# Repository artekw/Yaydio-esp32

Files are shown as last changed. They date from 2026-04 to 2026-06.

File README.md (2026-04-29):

# Yaydio 📻

**No more scratched CDs!**

**Yaydio** is a portable music player designed for kids, ditching the hassle of
CDs in favor of easy-to-use keycards.

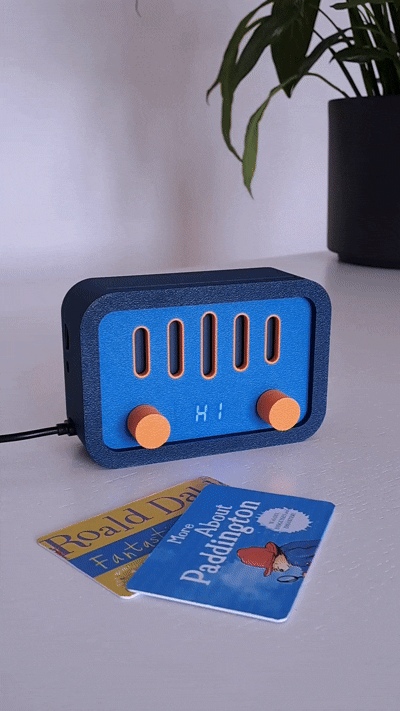
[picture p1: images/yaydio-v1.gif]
Yaydio
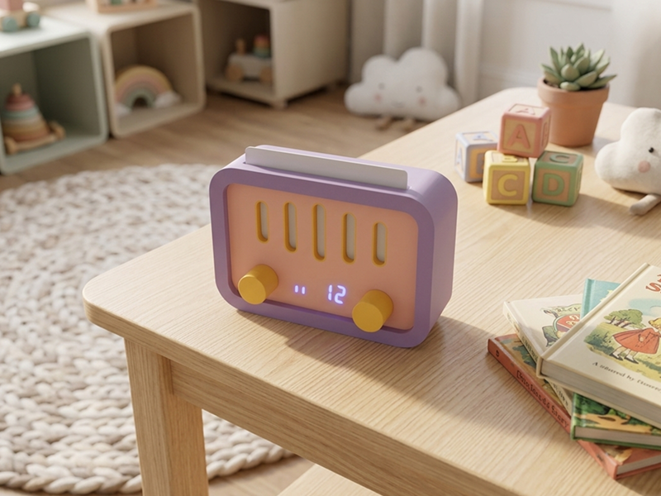
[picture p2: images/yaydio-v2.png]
Yaydio v2 (Based on real photo, scenery generated by AI)
|  |  |
| --- | --- |
| V1 | Battery powered V2 |

## ✨ Features

- **Keycard playback:** Insert a keycard to instantly play an album.
- **Simple controls:** Play/pause, next/previous track, volume up/down.
- **Audio options:** Built-in speaker or connect headphones via the 3.5mm jack.
- **Long battery life:** Over 12 hours of play time.
- **High capacity:**
  - Up to 999 songs per album
  - Up to 9999 albums
  - Up to 65535 songs in total
  - Supports micro SD cards up to 32GB.
- **MP3 compatibility:** Plays all your favorite MP3 files.
- **Affordable & accessible:** Works with cost-effective MF S50 RFID keycards.

## 🕹️ Controls

#### Play / pause

- Inserting a keycard into the **Yaydio** will automatically start the playback.
- Press the left knob to pause or resume the playback.
- Remove the keycard to stop the playback.

#### Volume

- Turn the left knob to increase or decrease the volume.

#### Next / previous track

- Turn the right knob to skip to the next or previous track.

#### Random playback

- Press the right knob to toggle random mode on or off.
- When enabled, the **Yaydio** will pick the next track from the album at
  random.

#### Assign an album to a keycard

1. Insert the keycard into the **Yaydio**.
2. Press the left and right knobs simultaneously.
3. Turn the right knob to select the album number.
4. Press the right knob to write the album number to the keycard.

## 💿 Adding albums (NEW WAY)

1. Download [Yaydio SD Flash](https://github.com/JakesMD/Yaydio-SD-Flash) for
   your platform.
2. Format the SD card to FAT16 or FAT32.
3. In the **Yaydio SD Flash** app:
   1. Create your albums.
   2. Create a new deck and select the albums to be on it.
   3. Write the deck to the SD card.

## 💿 Adding albums (OLD WAY)

#### Prepare the SD card

1. Format the SD card to FAT16 or FAT32 and name it `YAYDIO`.
2. Copy the `README.md` file onto the SD card.
3. Windows only: Download
   [DriveSort](https://www.anerty.net/software/file/DriveSort/?lang=en) and copy
   `DriveSort.exe` onto the SD card.
4. macOS only: Download [FatDriveSorter](https://fat-drive-sorter.netlify.app)
   and copy `FatDriveSorter.app` onto the SD card.

#### Copy albums to the SD card

1. Create a new folder named `0001`, where "1" represents the next album number.
2. Copy the album's songs into the folder you created.
3. Rename the first song of the album to `001.mp3`.
4. Repeat steps 1-3 for each album.

#### Sort the SD card

1. Windows only: Use `DriveSort` to sort the files alphabetically in the SD
   card's table.
   - Sort by `long name` and `ascending`.
   - Remember to press the save button.
   - You may need to sort every new folder individually and press save after
     each one.
2. macOS only: Use `FatDriveSorter` to sort the files alphabetically in the SD
   card's table.
   - Next to `Order:` select `Directories first`.
   - Tick the box next to `Case-sensitive:`.

## 🔨 Make your own

### 🧱 Parts

I've added an Amazon link for each part so you know what to look for. You'll
probably find the parts much cheaper in other stores.

- [x] 1 x Arduino Nano clone with USB-C port (pin headers not soldered on)
      ([Amazon.de](https://www.amazon.de/dp/B0D8WDV1K7))
- [x] 1 x PN532 NFC Module V3 ([Amazon.de](https://www.amazon.de/dp/B07YDG6X2V))
- [x] 1 x DY-SV5W Voice Module
      ([Amazon.de](https://www.amazon.de/dp/B09SZB73CG)) Note: Some modules
      don't come with a 1K Ohm resistor on the RXD pin. If this is the case,
      you'll have to connect D13 and the RXD pin with a 1K Ohm resistor
      ([see this](https://github.com/SnijderC/dyplayer/tree/main?tab=readme-ov-file#wiring-the-module)).
- [x] 1 x 4-digit 7-segment 0.36 inch display with TM1637 driver chip
      ([Amazon.de](https://www.amazon.de/dp/B0BCGF2R2T))
- [x] 2 x Rotary encoder with button and 15 mm D-shaft (not the KY-040 module!)
      ([Amazon.de](https://www.amazon.de/dp/B0DQKS8MBS))
- [x] 1 x Limit switch 12.8mm x 5.8mm
      ([Amazon.de](https://www.amazon.de/dp/B081TXMD4K))
- [x] 1 x Speaker 3W 8Ohms 70mm x 30mm x 15mm
      ([Amazon.de](https://amzn.eu/d/06Lj1tKR))
- [x] 1 x SM5308 battery charger module
      ([Amazon.de](https://www.amazon.de/dp/B0BGPGM4DH))
- [x] 1 x Battery 3.7V 3000mAh Li-ion 18650
      ([Amazon.de](https://www.amazon.de/dp/B0DZHL2WB6))
- [x] A bunch of 13.56 MHz MF S50 ISO14443 (Mifare Classic) RFID keycards
      ([Amazon.de](https://www.amazon.de/dp/B07TVJPTM7)) Note: If you plan on
      making multiple Yaydios sharing the same keycards, make sure you get
      keycards that aren't "magic". The cards must have a fixed UID that is not
      encrypted or reprogrammable.
- [x] Optional: 1 x Double-sided PCB board 20 x 80mm with 168 holes
      ([Amazon.de](https://www.amazon.de/dp/B0734XYJPM))
- [x] A bunch of wires ([Amazon.de](https://www.amazon.de/dp/B08MBXTRCG))

### 🧵 Wiring

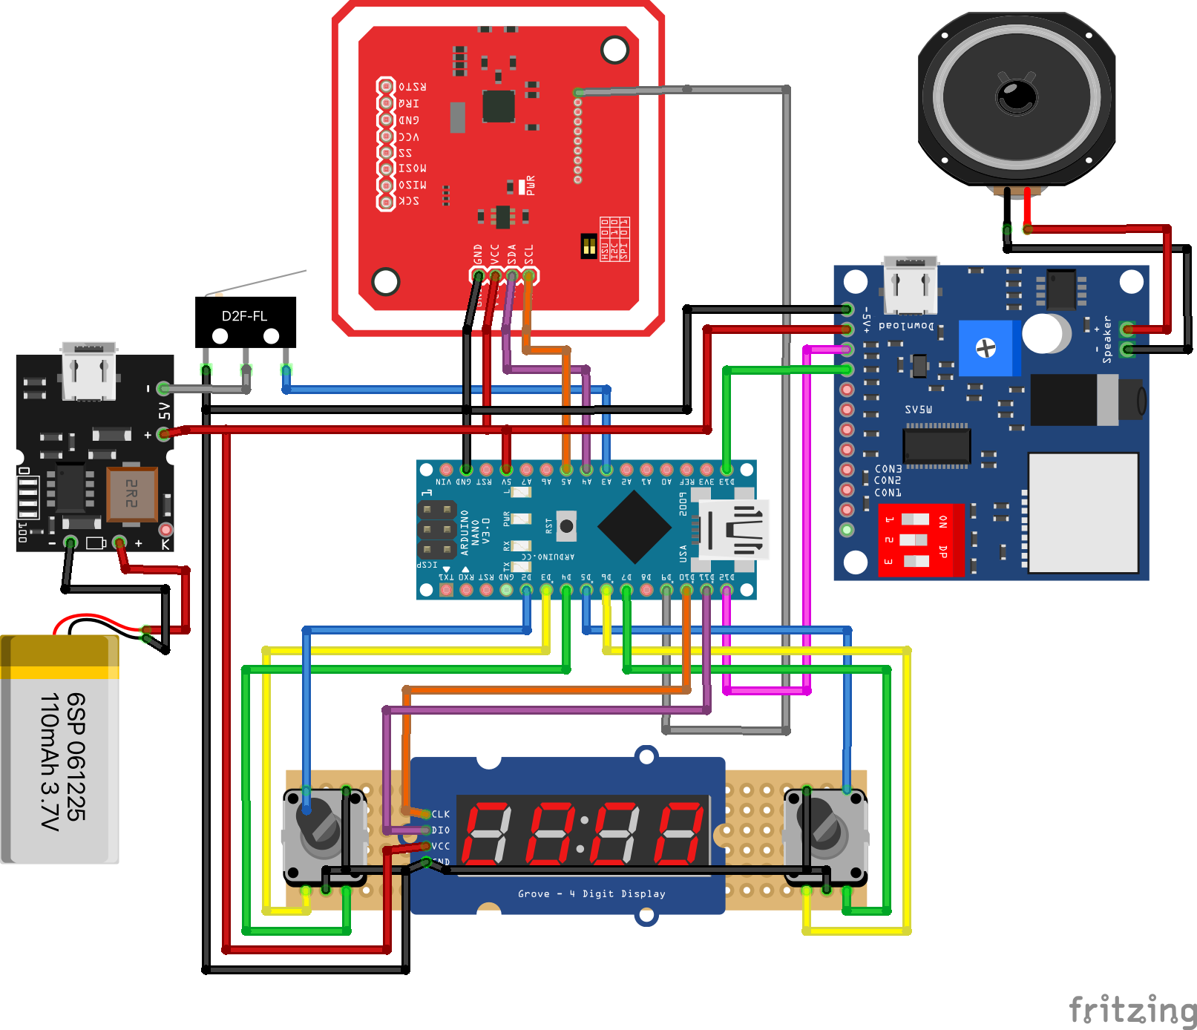
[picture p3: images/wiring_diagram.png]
Wiring Diagram


| Left Rotary Encoder | Arduino Nano |
| --- | --- |
| SW | D2 |
| SW GND | GND |
| DT | D3 |
| CLK | D4 |
| GND | GND |

| Right Rotary Encoder | Arduino Nano |
| --- | --- |
| SW | D5 |
| SW GND | GND |
| DT | D6 |
| CLK | D7 |
| GND | GND |

| 4-Digit 7-Segment 0.36 Inch TM1637 | Arduino Nano |
| --- | --- |
| CLK | D10 |
| DIO | D11 |
| GND | GND |
| 5V | 5V |

| Card Switch | |
| --- | --- |
| COM | Arduino GND |
| NO | Battery Module GND |
| NC | A3 |

| SM5308 Battery Module | |
| --- | --- |
| 5V | Arduino 5V |
| GND | Card Switch NO |
| B+ | Battery + |
| B- | Battery - |

| PN532 NFC Module V3 | Arduino Nano |
| --- | --- |
| GND | GND |
| VCC | 5V |
| SDA | A4 |
| SCL | A5 |
| RSTPDN | D9 |
| Switches: ON, OFF (I2C mode) | |

| DY-SV5W Voice Module | |
| --- | --- |
| - | Arduino GND |
| + | Arduino 5V  |
| TXD | Arduino D12 |
| RXD | Arduino D13 |
| Speaker + | Speaker + |
| Speaker - | Speaker - |
| Switches: OFF, OFF, ON (UART mode) | |

### 🏗️ Assembly

[yaydio.step](yaydio.step) contains the models of the 3D-printed parts. I have
also uploaded the [Bambu Studio project file](yaydio.3mf).

**Printer:** Bambu Lab A1 with AMS

**Nozzle:** 0.4mm

**Preset:** `0.20mm Standard @BBL A1` with supports enabled

**Filaments:**

- Bambu Lab PLA Matte Mandarin Orange (11300)
- Bambu Lab PLA Matte Marine Blue (11600)
- Bambu Lab PLA Matte Dark Blue (11602)
- or
- Bambu Lab PLA Matte Lemon Yellow (11400)
- Bambu Lab PLA Matte Sakura Pink (11201)
- Bambu Lab PLA Matte Lilac purple (11700)

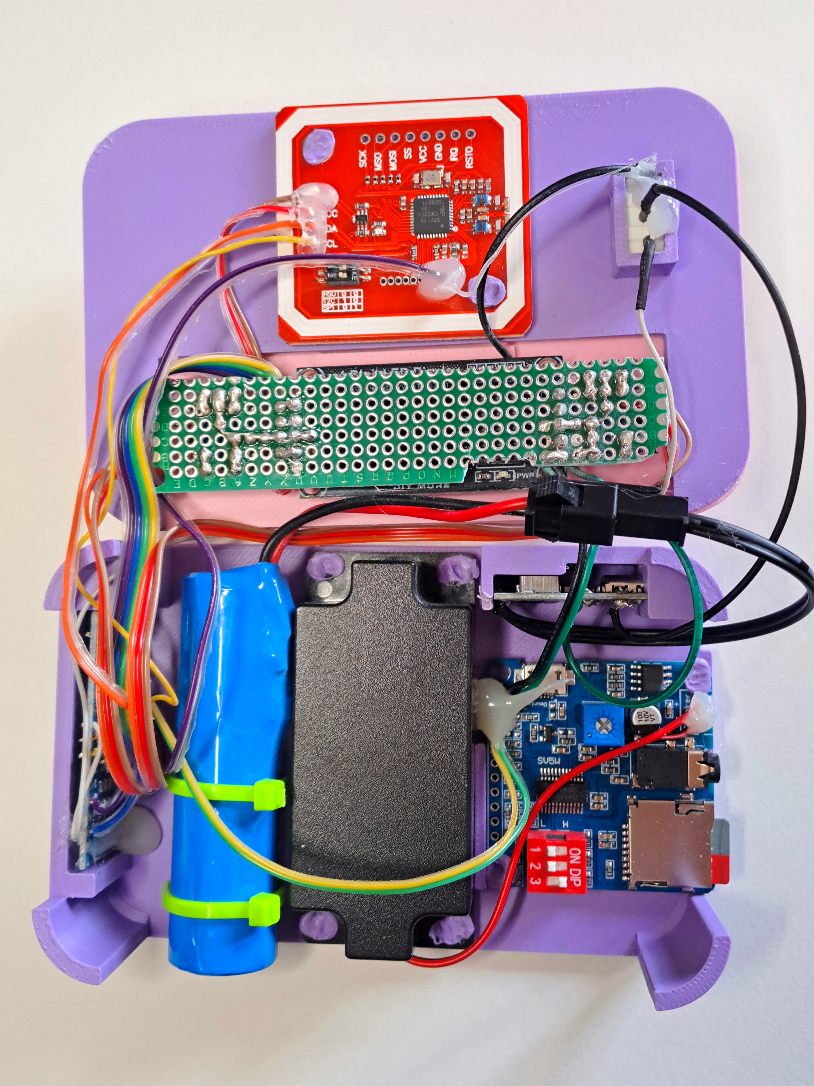
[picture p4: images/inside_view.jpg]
Inside view


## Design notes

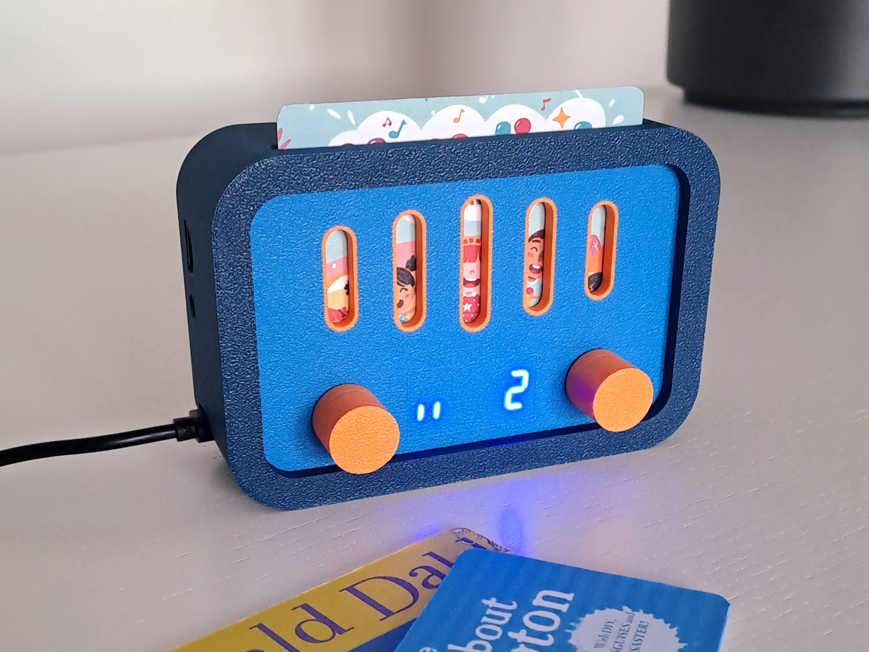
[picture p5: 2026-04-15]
images/yaydio-v1.jpg

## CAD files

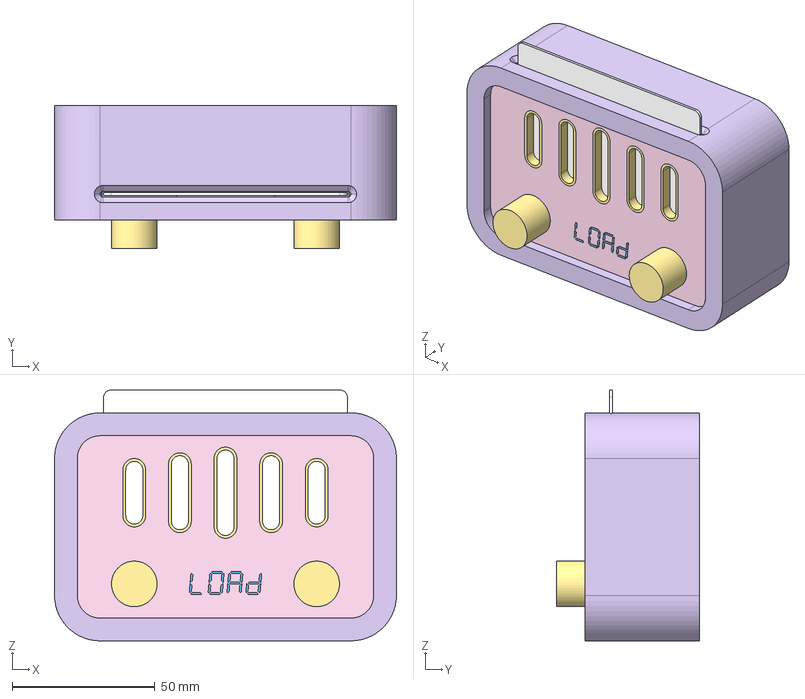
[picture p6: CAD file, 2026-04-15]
yaydio.step
120.0 x 50.0 x 88.0 mm
Card
NFC PN532
Battery
Speaker
Front plate
Knob x 2
Display text
NFC plate
Back plate

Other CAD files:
yaydio.3mf
yaydio.f3d

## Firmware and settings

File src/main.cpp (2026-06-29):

#include <Arduino.h>
#include <TM1637Display.h>

#include "button.h"
#include "config.h"
#include "display.h"
#include "mp3_player.h"
#include "nfc.h"
#include "rotary_encoder.h"

YButton cardBtn(CARD_BTN_PIN, LOW);  // LOW = karta włożona (normalny stan)

YButton leftBtn(LEFT_BTN_PIN);
YButton rightBtn(RIGHT_BTN_PIN);

YRotaryEncoder leftRotaryEncoder(LEFT_CLK_PIN, LEFT_DT_PIN);
YRotaryEncoder rightRotaryEncoder(RIGHT_CLK_PIN, RIGHT_DT_PIN);

YDisplay display(DISP_CLK_PIN, DISP_DIO_PIN);

YNFC nfc(NFC_IRQ_PIN, NFC_RST_PIN);

YMP3Player mp3Player(MP3_RX_PIN, MP3_TX_PIN);

enum YMODE {
    NO_CARD_MODE,
    READ_CARD_MODE,
    WRITE_CARD_MODE,
    PLAYER_MODE,
    SET_ALBUM_MODE,
    NO_ALBUM_MODE,
    FAIL_MODE,
};

YMODE mode = NO_CARD_MODE;
bool hasModeChanged = true;
bool isNewModeComing = false;

bool wasRightBtnReleased = false;

unsigned long lastUpdate = 0;
unsigned long currentMillis = 0;

uint8_t selectedAlbum = 1;

void updateTrackScreen() {
    display.showTrack(mp3Player.currentTrack(), mp3Player.isPlaying());
    lastUpdate = currentMillis;
}

void changeMode(YMODE newMode) {
    mode = newMode;
    isNewModeComing = true;
}

bool tryInitializePeripherals(int attempts = 5) {
    for (int i = 0; i < attempts; ++i) {
        if (nfc.begin() && mp3Player.begin()) {
            return true;
        }
        delay(500);
    }
    return false;
}

void setup() {
    Serial.begin(115200);
    Serial.println("Hi!");

    if (!tryInitializePeripherals()) {
        display.showFail();
        while (true);
    }
}

void loop() {
    cardBtn.loop();
    leftBtn.loop();
    rightBtn.loop();
    leftRotaryEncoder.loop();
    rightRotaryEncoder.loop();

    currentMillis = millis();

    switch (mode) {
        case NO_CARD_MODE:
            if (hasModeChanged) {
                mp3Player.stop();
                display.clear();
                Serial.println("MODE: NO_CARD");
            }
            if (cardBtn.isPressed()) {
                Serial.println("cardBtn pressed -> READ_CARD");
                changeMode(READ_CARD_MODE);
            }
            break;

        case READ_CARD_MODE:
            if (hasModeChanged) {
                display.showHi();
                mp3Player.stop();
                Serial.println("MODE: READ_CARD");
            }
            switch (nfc.read()) {
                case YNFC_NO_CARD:
                    Serial.println("NFC: no card");
                    changeMode(NO_CARD_MODE);
                    break;
                case YNFC_SUCCESS:
                    selectedAlbum = nfc.album();
                    Serial.printf("NFC: album=%d\n", selectedAlbum);
                    changeMode(selectedAlbum == 0 ? NO_ALBUM_MODE : PLAYER_MODE);
                    break;
                case YNFC_FAIL:
                    Serial.println("NFC: fail");
                    changeMode(FAIL_MODE);
                    break;
            }
            break;

        case WRITE_CARD_MODE:
            if (hasModeChanged) display.showLoading();
            switch (nfc.setAlbum(selectedAlbum)) {
                case YNFC_NO_CARD:
                    changeMode(NO_CARD_MODE);
                    break;
                case YNFC_SUCCESS:
                    if (selectedAlbum == 0) {
                        changeMode(NO_ALBUM_MODE);
                    } else {
                        changeMode(PLAYER_MODE);
                    }
                    break;
                case YNFC_FAIL:
                    changeMode(FAIL_MODE);
                    break;
            }
            break;

        case PLAYER_MODE:
            if (hasModeChanged) {
                Serial.println("MODE: PLAYER");
                mp3Player.playAlbum(selectedAlbum);
                Serial.printf("after playAlbum: isPlaying=%d track=%d\n", mp3Player.isPlaying(), mp3Player.currentTrack());
                updateTrackScreen();
            }

            if (cardBtn.isReleased()) {
                Serial.println("cardBtn released -> NO_CARD");
                changeMode(NO_CARD_MODE);
                break;
            }

            if (leftBtn.justReleased()) {
                mp3Player.togglePlayback();
                updateTrackScreen();
            }

            if (rightBtn.justReleased()) {
                display.showRandom(mp3Player.toggleRandom());
                lastUpdate = currentMillis;
            }

            if (leftBtn.isPressed() && rightBtn.isPressed()) {
                changeMode(SET_ALBUM_MODE);
                break;
            }

            if (leftRotaryEncoder.justTurnedCW()) {
                mp3Player.increaseVolume();
                // Serial.println("Vol Up");
            } else if (leftRotaryEncoder.justTurnedCCW()) {
                mp3Player.decreaseVolume();
                // Serial.println("Vol Down");
            }

            if (rightRotaryEncoder.justTurnedCW()) {
                mp3Player.next();
                updateTrackScreen();
            } else if (rightRotaryEncoder.justTurnedCCW()) {
                mp3Player.previous();
                updateTrackScreen();
            }

            if (currentMillis - lastUpdate > 1000) {
                Serial.printf("tick: isPlaying=%d track=%d cardBtn=%d\n", mp3Player.isPlaying(), mp3Player.currentTrack(), cardBtn.getState());
                updateTrackScreen();
            }

            break;

        case SET_ALBUM_MODE:
            if (hasModeChanged) {
                mp3Player.stop();
                wasRightBtnReleased = false;
                if (selectedAlbum == 0) selectedAlbum = 1;
                display.showAlbum(selectedAlbum);
            }

            if (cardBtn.isReleased()) {
                changeMode(NO_CARD_MODE);
                break;
            }

            if (rightBtn.justReleased()) {
                if (wasRightBtnReleased) {
                    changeMode(WRITE_CARD_MODE);
                } else {
                    wasRightBtnReleased = true;
                }

            } else if (selectedAlbum < 9999 && rightRotaryEncoder.justTurnedCW()) {
                selectedAlbum++;
                display.showAlbum(selectedAlbum);
            } else if (selectedAlbum > 0 && rightRotaryEncoder.justTurnedCCW()) {
                selectedAlbum--;
                display.showAlbum(selectedAlbum);
            }

            break;

        case NO_ALBUM_MODE:
            if (hasModeChanged) {
                mp3Player.stop();
                display.showBlank();
            }
            if (cardBtn.isReleased()) {
                changeMode(NO_CARD_MODE);
                break;
            }
            if (leftBtn.isPressed() && rightBtn.isPressed()) {
                changeMode(SET_ALBUM_MODE);
                break;
            }
            if (rightBtn.justReleased()) {
                changeMode(READ_CARD_MODE);
                break;
            }
            break;

        case FAIL_MODE:
            if (hasModeChanged) {
                lastUpdate = currentMillis;
                display.showFail();
                mp3Player.stop();
            } else if (currentMillis - lastUpdate > 2000) {
                changeMode(NO_CARD_MODE);
            }
            break;
    }

    if (isNewModeComing) {
        hasModeChanged = true;
        isNewModeComing = false;
    } else {
        hasModeChanged = false;
    }
}

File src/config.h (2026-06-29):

// Card contact switch
#define CARD_BTN_PIN A3

// Display
#define DISP_CLK_PIN 10
#define DISP_DIO_PIN 11
#define DISP_BRIGHTNESS 7  // 0 - 7

// Left button
#define LEFT_BTN_PIN 5

// Right button
#define RIGHT_BTN_PIN 2

// Left rotary encoder
#define LEFT_CLK_PIN 4
#define LEFT_DT_PIN 3

// Right rotary encoder
#define RIGHT_CLK_PIN 7
#define RIGHT_DT_PIN 6

// PN532 (NFC)
#define NFC_IRQ_PIN 8
#define NFC_RST_PIN 9

// DY-SV5W (MP3 Player)
#define MP3_RX_PIN 12
#define MP3_TX_PIN 13
#define MP3_INITIAL_VOLUME 20         // 0 - 30
#define MP3_EQ_MODE DY::eq_t::Normal  // Normal, Pop, Rock, Jazz, Classic

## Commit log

2026-04-07 Update wiring diagram
    [wiring_diagram.fzz]
2026-04-11 Flip card switch
2026-04-14 Power off NFC to save battery
2026-04-15 Add new CAD files
    [yaydio.f3d, yaydio.step]
2026-04-29 Upload Bambu Studio project file
    [yaydio.3mf]
2026-06-25 Sync working port for esp32
2026-06-29 Sync port for ESP32
